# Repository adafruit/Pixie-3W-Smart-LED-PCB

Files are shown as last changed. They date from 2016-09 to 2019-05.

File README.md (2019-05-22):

## Adafruit Pixie 3W Smart LED PCB
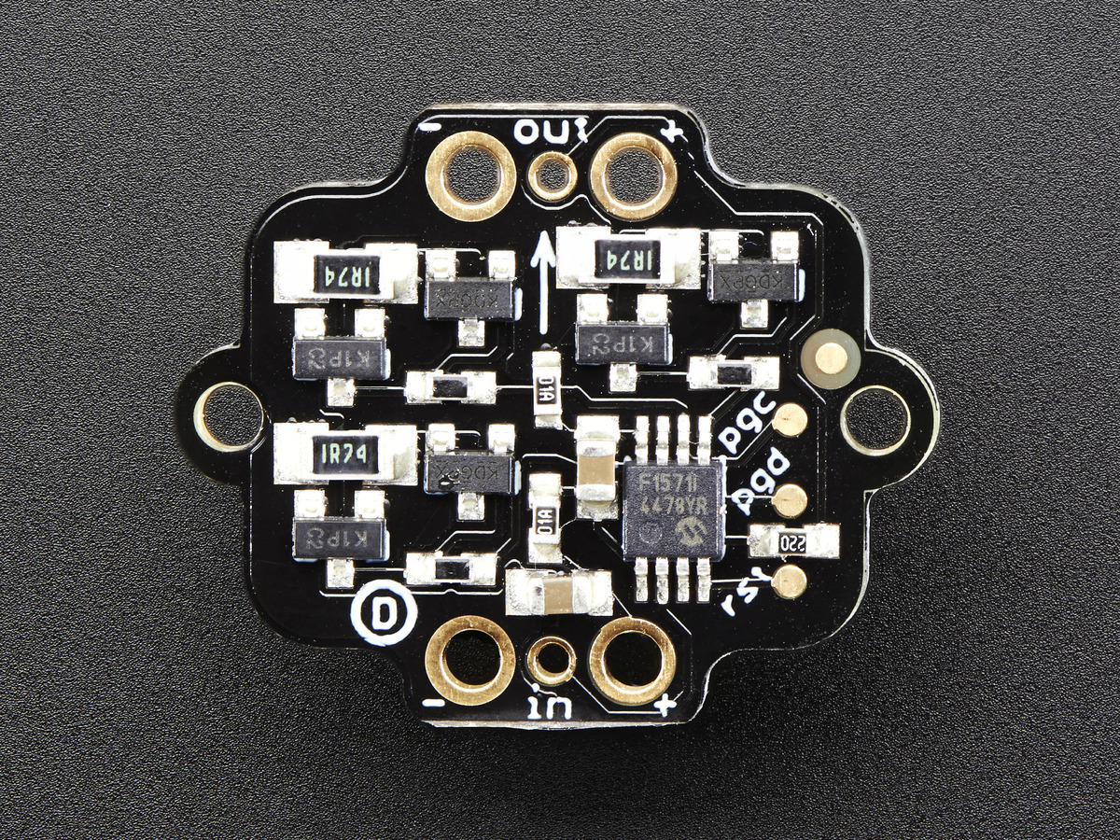
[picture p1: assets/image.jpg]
<a href="http://www.adafruit.com/products/2741"><br/>
Click here to purchase one from the Adafruit shop</a>

NeoPixels are plenty bright, suuuure. BUT ARE THEY 3 WATTS BRIGHT? No! They are not! That's why you need a Pixie. These chainable smart LEDs are not only super-smart, they are ridonkulously bright with 3W total, compared to 0.2W of a 'standard' NeoPixel. Designed by Ytai Ben-Tsvi, these are the ultimate in LEDs.

Each Pixie not only contains that aforementioned 3W LED, it also has a Microchip PIC microcontroller. You send it the color you want to appear at standard 115200 baud (1 byte per color). You can send a longer string of pixel data and it will 'forward' along the messages so you can chain them like a shift register. You only have to send the data once per color change. Once set, the microcontroller does all the PWM handling for you.

PCB files for the Pixie 3W Smart LED. The format is EagleCAD schematic and board layout
- http://www.adafruit.com/products/2741

### License

Adafruit invests time and resources providing this open source design, please support Adafruit and open-source hardware by purchasing products from [Adafruit](https://www.adafruit.com)!

All text above must be included in any redistribution

Designed by Limor Fried/Ladyada for Adafruit Industries.
Creative Commons Attribution/Share-Alike, all text above must be included in any redistribution. 
See license.txt for additional information.

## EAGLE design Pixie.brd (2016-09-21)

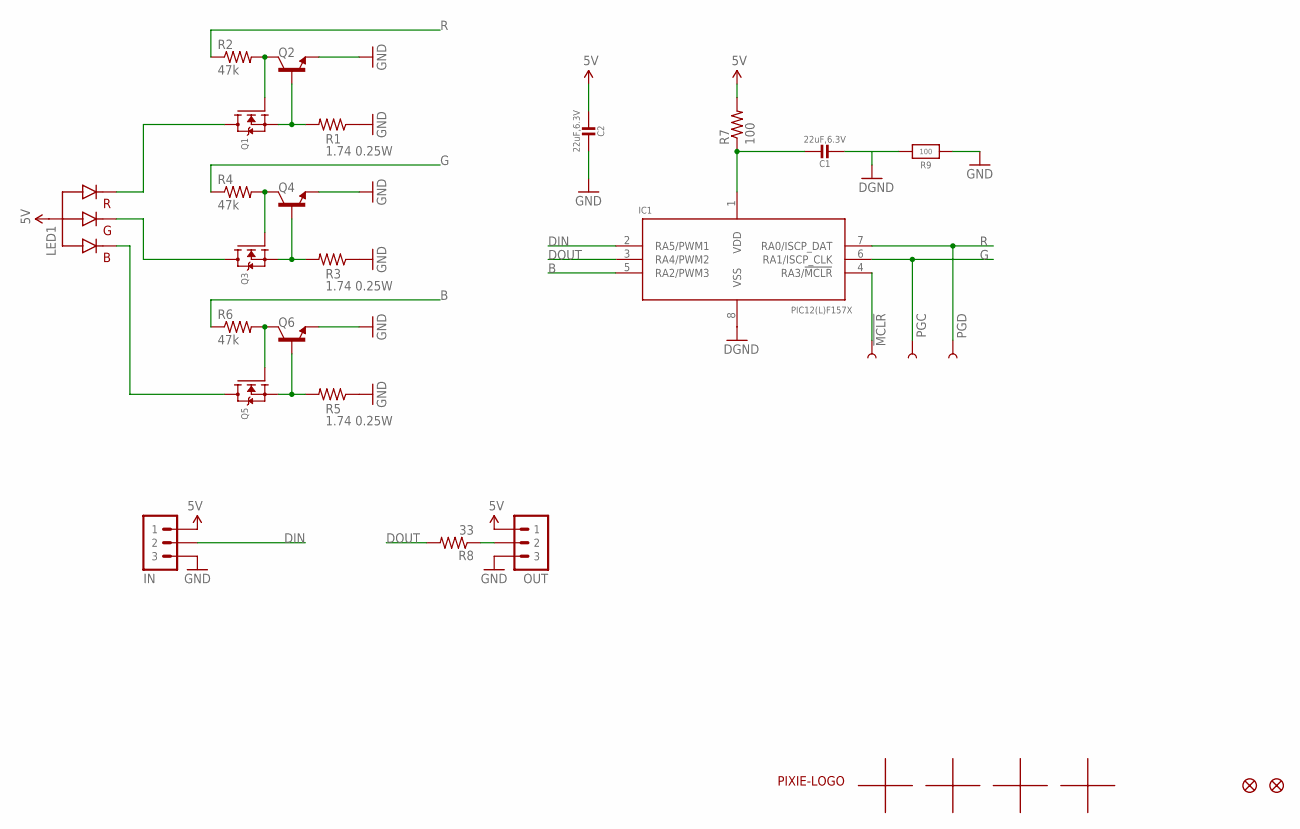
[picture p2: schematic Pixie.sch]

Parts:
!MCLR: TEST-POINT3X4; PAD.03X.04
C1, C2: 22uF,6.3V; _0805MP
IC1: PIC12(L)F157X; MSOP-8
IN: M030.1PWR+SIG; 1X03-0.1PWR+SIG
LED1: RGBLED_CA; RGBLED3W4PIN
OUT: M030.1PWR+SIG; 1X03-0.1PWR+SIG
PGC: TEST-POINT3X4; PAD.03X.04
PGD: TEST-POINT3X4; PAD.03X.04
Q1, Q3, Q5: IRLML2060TRPBF; SOT23-3
Q2, Q4, Q6: MMBT2222A; SOT23-3
R1, R3, R5: 1.74 0.25W; 1206
R2, R4, R6: 47k; 0603-RES
R7: 100; 0603-RES
R8: 33; 0603-RES
R9: 100; _0603MP
U$1, U$2, U$3, U$4: ALIGN_CROSS
U$5: PIXIE-LOGO
U$6, U$7: FIDUCIAL""; FIDUCIAL_1MM

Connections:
5V: C2.2, IN.P$1 (1), LED1.ANODE (VCC), OUT.P$1 (1), R7.2
B: IC1.5 (RA2/PWM3), R6.1
DGND: C1.2, IC1.8 (VSS), R9.2
DIN: IC1.2 (RA5/PWM1), IN.P$2 (2)
DOUT: IC1.3 (RA4/PWM2), R8.2
G: IC1.6 (RA1/ISCP_CLK), PGC.P$1, R4.1
GND: C2.1, IN.P$3 (3), OUT.P$3 (3), Q2.2 (E), Q4.2 (E), Q6.2 (E), R1.1, R3.1, R5.1, R9.1
unnamed: LED1.R (RED), Q1.3 (D)
unnamed: LED1.G (GREEN), Q3.3 (D)
unnamed: LED1.B (BLUE), Q5.3 (D)
unnamed: Q1.2 (S), Q2.1 (B), R1.2
unnamed: Q3.2 (S), Q4.1 (B), R3.2
unnamed: OUT.P$2 (2), R8.1
unnamed: !MCLR.P$1, IC1.4 (RA3/!MCLR)
unnamed: Q5.1 (G), Q6.3 (C), R6.2
unnamed: Q3.1 (G), Q4.3 (C), R4.2
unnamed: C1.1, IC1.1 (VDD), R7.1
unnamed: Q5.2 (S), Q6.1 (B), R5.2
unnamed: Q1.1 (G), Q2.3 (C), R2.2
R: IC1.7 (RA0/ISCP_DAT), PGD.P$1, R2.1

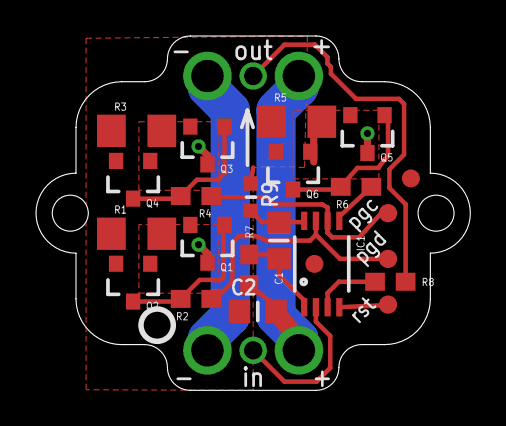
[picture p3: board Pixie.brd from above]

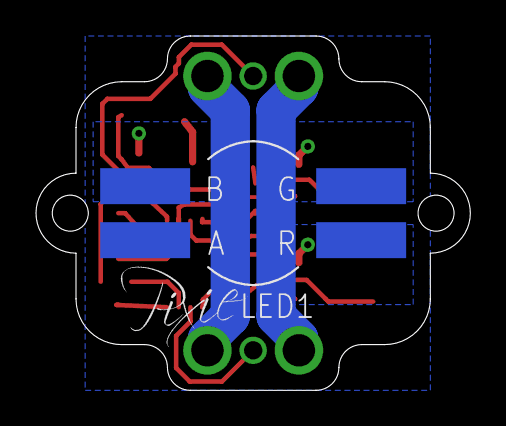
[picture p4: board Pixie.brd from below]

Board: 2 copper layers, 24.1 x 19.7 mm, 32 parts (2 on the bottom side), 20 nets.

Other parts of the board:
U$8: PCBFEAT-REV-040

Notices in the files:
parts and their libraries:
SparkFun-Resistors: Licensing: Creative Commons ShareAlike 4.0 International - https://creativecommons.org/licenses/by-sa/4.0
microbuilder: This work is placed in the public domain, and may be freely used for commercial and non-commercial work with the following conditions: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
